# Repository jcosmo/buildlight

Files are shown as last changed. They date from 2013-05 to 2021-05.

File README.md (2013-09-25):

Buildlight 
==========
Arduino Uno based build light for Jenkins.

Arduino Uno has:
 - 6 PWM pins - 3,5,6,9,10,11
 - 6 Digital pins - 2,4,7,8,12,13
 - 6 Analog pins

Intend to support lights:
 - RGB: 3,5,6 + 5V
 - RGB: 9,10,11 + 5V
 - Shiftbrite: 7,8,12,13 + Pwr + Gnd
 - 8 * single colour led: 3xR, 2xG, 3xY: 2,4, A0->A5

Possible that digital pins 0 & 1 might be usable, but if you can't work with 11 lights then you're stuffed.
  
Specs for lights
  - Common Anode 4 pin Tri Colour
     Red: 2 -> 2.2 V
     Green: 3 -> 3.2 V
     Blue: 3 -> 3.2 V
  
  - Red led: No details, so presuming 2V -> 3.2V
  - Green led: No details, so presuming 2V -> 3.2V
  - Yellow led: No details, so presuming 2V -> 3.2V

Aim to pull about 20mA:  R = (5-Vl)/0.02
  3/0.02 => 150 Ohm
  1.8/0.02 => 90 Ohm
  
If we use 100Ohm, then current will be: I = (5-Vl/R)
  3/100 => 30mA
  1.8/100 => 18mA.
Both within tolerance of the Arduino pins (40mA max)
Concern? of drawing too much from one set of pins, or too much to the ground pin if multiple lights are on.

Experimentation in comparing 100 and 200 ohm resistors showed not enough difference to warrant 100Ohm for yellow and green.
So will go 200 and lower the current.  Red is notably dimmer than the others in all cases so will use a 100Ohm for it to increase brightness.

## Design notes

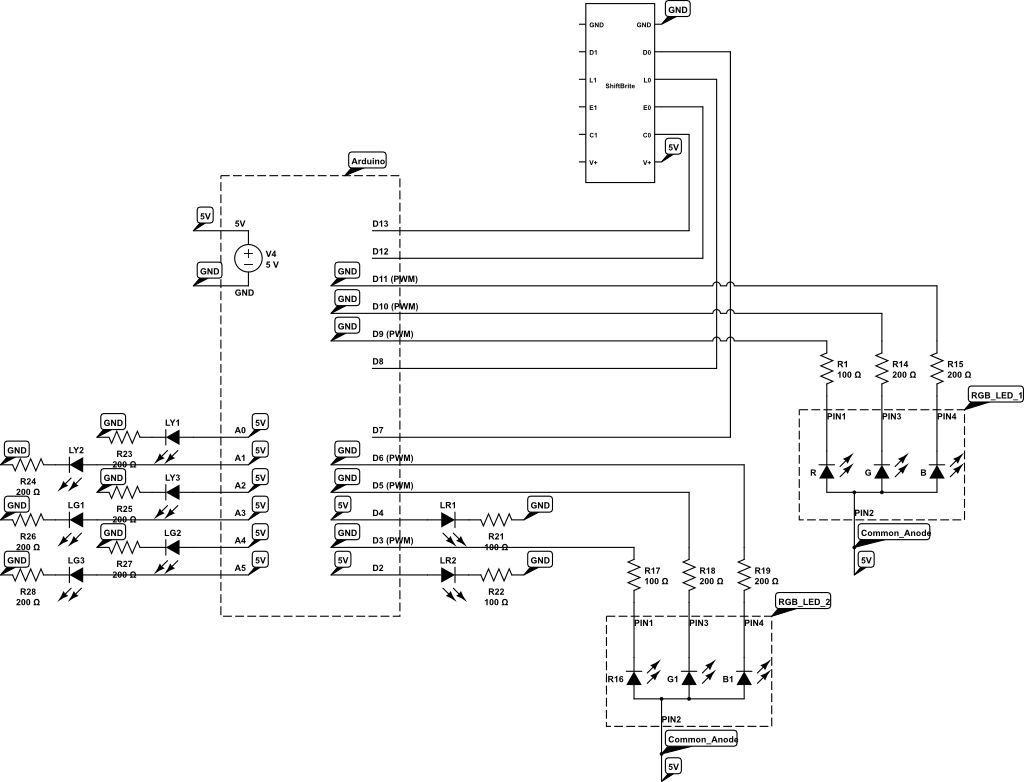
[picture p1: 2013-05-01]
circuit.png

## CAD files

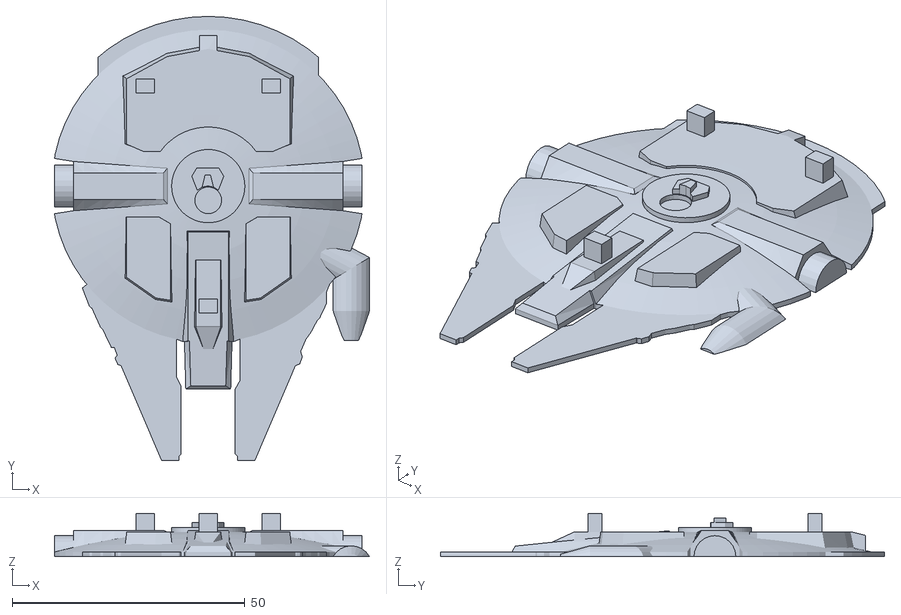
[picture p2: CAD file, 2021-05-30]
case/falcon2_bottom2.stl
67.6 x 95.3 x 9.28

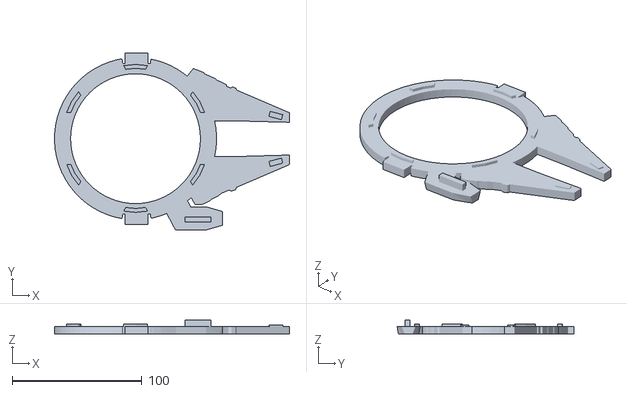
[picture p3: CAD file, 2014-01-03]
case/case_middle.stl
181.0 x 136.3 x 11.0

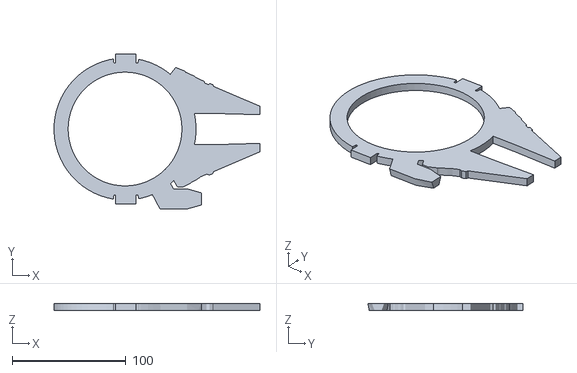
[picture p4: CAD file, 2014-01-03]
case/case_middle_noclips.stl
181.0 x 136.3 x 6.00

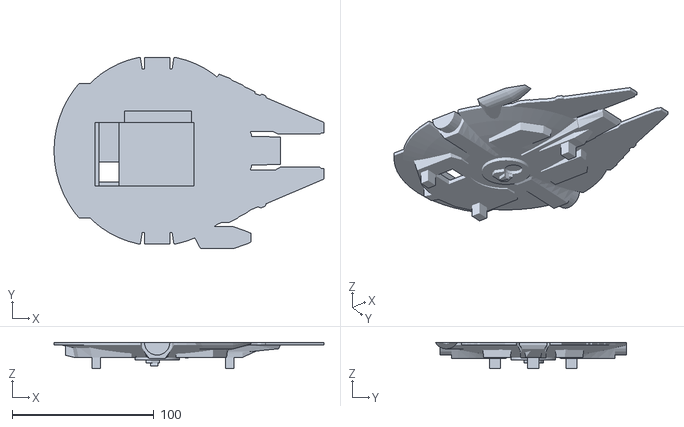
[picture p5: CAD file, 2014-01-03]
case/case_bottom_cleaned.stl
190.7 x 135.2 x 18.6

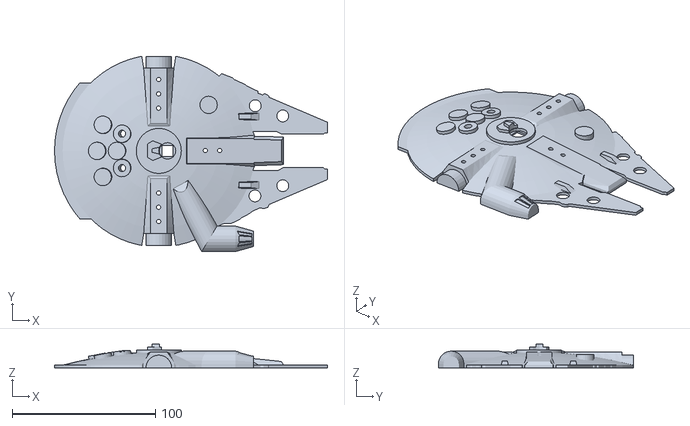
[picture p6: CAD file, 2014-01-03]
case/case_top_cleaned.stl
190.7 x 136.3 x 16.7

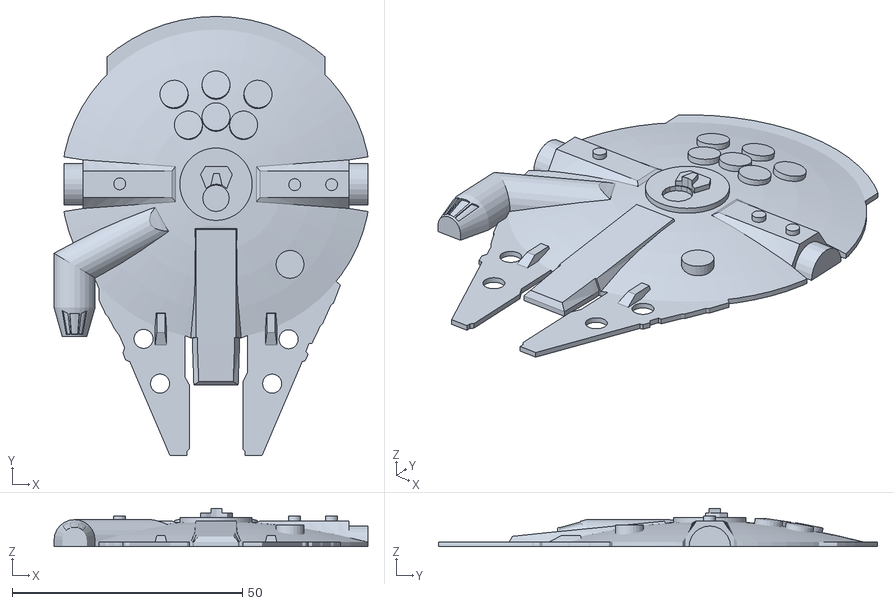
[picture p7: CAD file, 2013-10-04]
case/falcon2top_fixed.stl
68.2 x 95.3 x 8.35

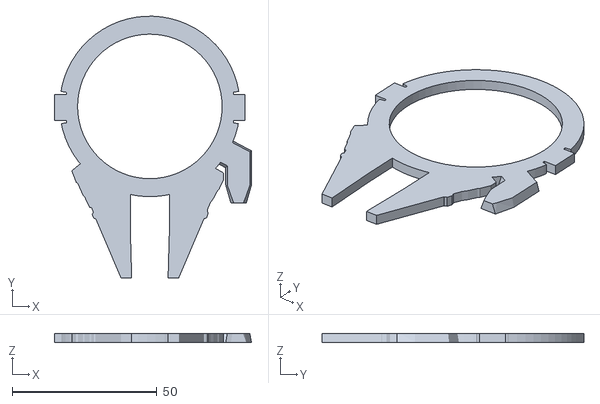
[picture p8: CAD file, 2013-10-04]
case/falcon2middle_fixed.stl
68.2 x 90.5 x 3.00

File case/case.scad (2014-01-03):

// Axis indexes;
X = 0; Y = 1; Z = 2;

FalconScale = 2;
FalconMOffset = [0,-2.41,0]; // Relative to FalconTop
FalconBOffset = [0.3,0,-3]; // Relative to FalconTop

FalconOffset = [FalconScale * 8.2, FalconScale * -1.1, FalconScale * 1.5]; // To Centre the Falcon
//ArduinoOffset = [0, 15+9.25, FalconScale * FalconBOffset[Z]/2];   // Relative to centred falcon
ArduinoOffset = [18, 5, 5.6];   // Relative to centred falcon
LedOffset = [-15.5, -10.5, 9.5];   // Relative to centred falcon

//echo( "Falcon at ", FalconScale, "x is ", (FalconScale * 95), " long, ", (FalconScale*70), " wide and ", (FalconScale*22), " tall" );
// scalebar();
difference() {
union() {
translate(FalconOffset) falcon(true,false,false);
//translate(ArduinoOffset) rotate([180,0,180]) arduino();
//translate(LedOffset) shiftbrite();
}
translate(ArduinoOffset) rotate([180,0,180]) arduino_cutout();
translate(LedOffset) shiftbrite_cutout();
wire_cutout();
}

module wire_cutout() {
  translate([-50,-25,-10]) cube([70,45,10]);
  translate([-40,-15,-20]) cylinder(r=7,h=10);
}

module arduino_cutout() {
  translate([0,-2.5,0] ) cube( [47, 25.5, 12.8] ); 
}

module shiftbrite_cutout() {
  union() {
    shiftbrite();
    translate([0,0,-10]) cube([31,21,11.4]);
  }
}

module arduino() {
  Board = [43.5, 18.5, 4.8];
  Usb = [9.5, 7.6, 3.75];
  Pins = [5, 7.5, 8.25];
  PinsWithSpace = [Pins[X]+3, Pins[Y]+3, Pins[Z]+2];
  
  UsbOffset = [Board[X] - (Usb[X] - 1.9), centre(Board, Usb, Y), Board[Z]];
  PinsOffset = [0, centre(Board, PinsWithSpace, Y), Board[Z]];

  color( "Black", 0.8) {
    cube( Board ); 
    translate( UsbOffset ) cube( Usb );
    translate( PinsOffset ) cube( PinsWithSpace );
  }
}

module shiftbrite() {
  Ledbase = [7.7,7.7,4.5];
  Leddome = 4.8;
  Board = [31,21,1.5];
  Pins = [16, 2.5, 12];
  
  LedbaseOffset = [centre(Board, Ledbase, X), centre(Board, Ledbase, Y), Board[Z]];
  LeddomeOffset = [Board[X]/2, Board[Y]/2, Ledbase[Z] + LedbaseOffset[Z]];
  Pin1Offset = [centre(Board, Pins, X), 1, -9];
  Pin2Offset = [centre(Board, Pins, X), Board[Y] - Pins[Y] - 1, -9];
  
  color( "Black", 1 ){
    cube(Board);
    translate( LedbaseOffset ) cube( Ledbase );
    translate( LeddomeOffset ) sphere( r=Leddome/2, $fn=20 );
  }
  color ("White", 1) {
    translate( Pin1Offset ) cube( Pins );
    translate( Pin2Offset ) cube( Pins );
  }
}

// holes at given spacing
module holes(count, size, spacing) {
  union() {
    for (x = [0:count-1]) translate([spacing*x,0,0]) cylinder(h=10,r=(size/FalconScale)/2, $fn=40);
  }
}

module middle_to_top_clips() {
  translate(FalconMOffset) {
    translate([1.2,14,0]) difference() {
      cylinder(r=28.5, h=1);
      cylinder(r=27, h=1);
      for( x = [0:5] ) rotate([0,0,x*60]) cube([20,60,5], center=true);
    }
    translate([-8,-40,0]) rotate([0,0,15]) cube([2,5,1], center=true);
    translate([10,-40,0]) rotate([0,0,-15]) cube([2,5,1], center=true);
    translate([-30,-10,0]) cube([2,10,5], center=true);
  }
}            

module falcon(top, middle, bottom) {
  O = 0.5;
  
  scale(FalconScale)
    rotate([0,0,90]) {
      if (top) {
        //color( "Salmon", O) 
        difference() {
          import( "falcon2top_fixed.stl" );
          translate([15,9,5.64]) cube([15,5,3]);	// remove bobbles on right
          translate([-26,9,5.64]) cube([15,5,3]);	// remove bobbles on left
          translate([16,11.3,-4]) holes(3, 3, 5);	
          translate([-23.6,11.3,-4]) holes(3, 3, 5);	
          translate([1.2,-10,-4]) rotate([0,0,90]) holes(2, 3, 5);
          translate([-4.9,23,-2]) rotate([-8,0,0]) holes(2, 5, 12);
          middle_to_top_clips();
        }
      }
      if (middle) {
//      color( "DarkSalmon", O) 
        translate(FalconMOffset) {
          rotate([0,180,0]) import( "falcon2middle_fixed.stl" );
        }
        //middle_to_top_clips();
      }
      if (bottom) {
//      color( "Salmon", O);
        translate(FalconBOffset) rotate([0,180,0]) import( "falcon2bottom_fixed.stl" );
      }
    }
}

module scalebar() {
  scale(FalconScale) {
    color("Blue", 1) {
      translate([-48,-1,-1]) cube([95, 2, 2]);
      rotate([0,0,90]) translate([-35,-1,-1]) cube([70, 2, 2]);
      rotate([0,90,0]) translate([-8,-1,-1]) cube([22, 2, 2]);
    }
  }
}

// Centre B in A along given axis
function centre( A, B, axis ) =
  (A[axis] - B[axis]) / 2;

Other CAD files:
case/case_bottom.stl
case/case_top.stl
case/falcon2bottom_fixed.stl
case/falcon2_middle.stl
case/falcon2_bottom.stl
case/falcon2_top.stl
case/bottom.skp
case/top.skp

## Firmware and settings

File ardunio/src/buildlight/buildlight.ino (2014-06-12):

/*
  Buildlight controller.

  Buildlight has RGB1, RGB2, Shiftbrite, 2xR + 3xG + 3xY led

  Commands:
      [light] ON/OFF/FLASH [Colour]?
      off  = everything off until next command
      flash [speed]
      sample

  [light]: T0, T1, S0, R0, R1, G0, G1, G2, Y0, Y1, Y2  (T => TriColour, S => ShiftBrite)
  [colour]: R,G,B optional, only used on T#, S#
  [speed]: milliseconds for each phase of a flash
*/

#include "HughesyShiftBrite.h"

typedef struct colour { unsigned int r; unsigned int g; unsigned int b; } Colour;
typedef struct { Colour colour; unsigned int pins[3]; bool on; bool flash; } RGBLed;
typedef struct { Colour colour; Colour offColour;
                 unsigned int data; unsigned int latch; unsigned int enable; unsigned int clock;
                 bool on; bool flash; HughesyShiftBrite hsb; } ShiftBrite;

RGBLed rgb_leds[2];
ShiftBrite shiftBrite[1];

unsigned int led_pins[] = {A5,2,4,A4,A1,A0,A2,A3};
bool led_on[8];
bool led_flash[8];
int RED_OFFSET = 0;
int YEL_OFFSET = RED_OFFSET + 4;
int GRN_OFFSET = YEL_OFFSET + 2;
int flash_speed = 250;
bool sleeping;

// RGB led colours for convienence
Colour RED = {0,255,255};
Colour GREEN = {255,0,255};
Colour BLUE = {255,255,0};
Colour YELLOW = {0,0,255};
Colour PURPLE = {0,255,0};
Colour CYAN = {255,0,0};
Colour WHITE = {0,0,0};
Colour SB_BLACK = {0,0,0};

void update_led( unsigned int idx )
{
  digitalWrite( led_pins[idx], led_on[idx] ? HIGH : LOW );
}

void set_led_flash( unsigned int idx )
{
  led_flash[idx] = true;
}

void toggle_led_state( unsigned int idx )
{
  led_on[idx] = !led_on[idx];
  update_led( idx );
}

void set_led_on( unsigned int idx )
{
  led_flash[idx] = false;
  led_on[idx] = true;
  update_led(idx);
}

void set_led_off( unsigned int idx )
{
  led_flash[idx] = false;
  led_on[idx] = false;
  update_led(idx);
}

void update_rgb( unsigned int idx )
{
  if ( rgb_leds[idx].on )
  {
    analogWrite(rgb_leds[idx].pins[0],rgb_leds[idx].colour.r);
    analogWrite(rgb_leds[idx].pins[1],rgb_leds[idx].colour.g);
    analogWrite(rgb_leds[idx].pins[2],rgb_leds[idx].colour.b);
  }
  else
  {
    analogWrite(rgb_leds[idx].pins[0],255);
    analogWrite(rgb_leds[idx].pins[1],255);
    analogWrite(rgb_leds[idx].pins[2],255);
  }
}

void set_rgb_colour_rgb( unsigned int idx, unsigned int r, unsigned int g, unsigned int b )
{
  rgb_leds[idx].colour.r = r;
  rgb_leds[idx].colour.g = g;
  rgb_leds[idx].colour.b = b;
  update_rgb(idx);
}

void set_rgb_colour( unsigned int idx, struct colour c )
{
  rgb_leds[idx].colour.r = c.r;
  rgb_leds[idx].colour.g = c.g;
  rgb_leds[idx].colour.b = c.b;
  update_rgb(idx);
}

void set_rgb_on( unsigned int idx )
{
  rgb_leds[idx].flash = false;
  rgb_leds[idx].on = true;
  update_rgb(idx);
}

void set_rgb_off( unsigned int idx )
{
  rgb_leds[idx].flash = false;
  rgb_leds[idx].on = false;
  update_rgb(idx);
}

void set_rgb_flash( unsigned int idx )
{
  rgb_leds[idx].flash = true;
}

void toggle_rgb_state( unsigned int idx )
{
  rgb_leds[idx].on = !rgb_leds[idx].on;
  update_rgb( idx );
}

void update_shiftBrite( unsigned int idx )
{
  if ( shiftBrite[idx].on )
    shiftBrite[idx].hsb.sendColour(shiftBrite[idx].colour.r,shiftBrite[idx].colour.g,shiftBrite[idx].colour.b);
  else
    shiftBrite[idx].hsb.sendColour(shiftBrite[idx].offColour.r,shiftBrite[idx].offColour.g,shiftBrite[idx].offColour.b);
}

float SB_RGB_SCALE = 1023/255;
void set_shiftBrite_colour( unsigned int idx, struct colour c )
{
  shiftBrite[idx].colour.r = (int)((255-c.r) * SB_RGB_SCALE);
  shiftBrite[idx].colour.g = (int)((255-c.g) * SB_RGB_SCALE);
  shiftBrite[idx].colour.b = (int)((255-c.b) * SB_RGB_SCALE);
  update_shiftBrite(idx);
}

void set_shiftBrite_offColour( unsigned int idx, struct colour c )
{
  shiftBrite[idx].offColour.r = (int)((255-c.r) * SB_RGB_SCALE);
  shiftBrite[idx].offColour.g = (int)((255-c.g) * SB_RGB_SCALE);
  shiftBrite[idx].offColour.b = (int)((255-c.b) * SB_RGB_SCALE);
}

void set_shiftBrite_flash( unsigned int idx )
{
  shiftBrite[idx].flash = true;
}

void toggle_shiftBrite_state( unsigned int idx )
{
  shiftBrite[idx].on = !shiftBrite[idx].on;
  update_shiftBrite(idx);
}

void set_shiftBrite_on( unsigned int idx )
{
  shiftBrite[idx].flash = false;
  if ( !shiftBrite[idx].on )
  {
    shiftBrite[idx].on = true;
    update_shiftBrite(idx);
  }
}

void set_shiftBrite_off( unsigned int idx )
{
  shiftBrite[idx].flash = false;
  set_shiftBrite_offColour( idx, (struct colour){255-SB_BLACK.r, 255-SB_BLACK.b, 255-SB_BLACK.g} );
  if ( shiftBrite[idx].on )
  {
    shiftBrite[idx].on = false;
    update_shiftBrite(idx);
  }
}

void sample_pattern()
{
  set_led_on( RED_OFFSET + 0 );
  set_led_flash( RED_OFFSET + 0 );
  set_led_flash( RED_OFFSET + 1 );
  set_led_flash( RED_OFFSET + 2 );
  set_led_flash( RED_OFFSET + 3 );
  set_led_on( GRN_OFFSET + 0 );
  set_led_flash( GRN_OFFSET + 0 );
  set_led_flash( GRN_OFFSET + 1 );
  
  set_led_flash( YEL_OFFSET + 0 );
  set_led_on( YEL_OFFSET + 1 );
  set_led_flash( YEL_OFFSET + 1 );

  set_led_on( RED_OFFSET + 1 );
  set_led_on( GRN_OFFSET + 1 );

  set_rgb_colour(0, WHITE );
  set_rgb_colour(1, PURPLE );
  set_rgb_on(1);
  set_rgb_flash(0);

  set_shiftBrite_colour(0, GREEN);
  set_shiftBrite_offColour(0, PURPLE);
  set_shiftBrite_flash(0);
}

void setup()
{
  rgb_leds[0] = (RGBLed){{255,255,255}, {3,6,5}, false, false};
  rgb_leds[1] = (RGBLed){{255,255,255}, {9,11,10}, false, false};
  shiftBrite[0] = (ShiftBrite){SB_BLACK, SB_BLACK, 7,8,12,13, false, false};

  for( unsigned int i = 0; i < sizeof(led_pins)/sizeof(led_pins[0]); i++)
  {
    led_on[i] = false;
    led_flash[i] = false;
    pinMode(led_pins[i], OUTPUT);
    update_led(i);
  }

  for( unsigned int i = 0; i < sizeof(rgb_leds)/sizeof(rgb_leds[0]); i++)
  {
    pinMode(rgb_leds[i].pins[0], OUTPUT);
    pinMode(rgb_leds[i].pins[1], OUTPUT);
    pinMode(rgb_leds[i].pins[2], OUTPUT);
    update_rgb(i);
  }

  for( unsigned int i = 0; i < sizeof(shiftBrite)/sizeof(shiftBrite[0]); i++)
  {
    pinMode(shiftBrite[i].enable, OUTPUT);
    pinMode(shiftBrite[i].clock, OUTPUT);
    pinMode(shiftBrite[i].data, OUTPUT);
    pinMode(shiftBrite[i].latch, OUTPUT);
    shiftBrite[i].hsb = HughesyShiftBrite( shiftBrite[i].data, shiftBrite[i].latch, shiftBrite[i].enable, shiftBrite[i].clock );
    update_shiftBrite(i);
  }  
  
  Serial.begin(9600);
  Serial.setTimeout(100);
}

void loop()
{
  if ( sleeping )
    delay( 30 * 1000 );
  else
  {
    for( unsigned int i = 0; i < sizeof(led_pins)/sizeof(led_pins[0]); i++)
      if ( led_flash[i] )
        toggle_led_state( i );

    for( unsigned int i = 0; i < sizeof(rgb_leds)/sizeof(rgb_leds[0]); i++)
      if ( rgb_leds[i].flash )
        toggle_rgb_state( i );

    for( unsigned int i = 0; i < sizeof(shiftBrite)/sizeof(shiftBrite[0]); i++)
      if ( shiftBrite[i].flash )
        toggle_shiftBrite_state( i );

    delay(flash_speed);
  }
}

void all_off()
{
  for( unsigned int i = 0; i < sizeof(led_pins)/sizeof(led_pins[0]); i++)
    set_led_off( i );

  for( unsigned int i = 0; i < sizeof(rgb_leds)/sizeof(rgb_leds[0]); i++)
    set_rgb_off( i );

  for( unsigned int i = 0; i < sizeof(shiftBrite)/sizeof(shiftBrite[0]); i++)
    set_shiftBrite_off( i );
}

void led_cmd( unsigned int offset, char *cmd )
{
  int idx;
  char op[80];
  if ( 2 == sscanf(cmd + sizeof(char), "%d %s", &idx, op))
  {
    if ( idx + offset >= sizeof(led_pins)/sizeof(led_pins[0]))
    {
      Serial.println(String("Invalid led pin index: [") + idx + "]");
      return;
    }
    if ( String("ON").equalsIgnoreCase(op) )
      set_led_on( idx + offset );
    else if ( String("OFF").equalsIgnoreCase(op) )
      set_led_off( idx + offset );
    else if ( String("FLASH").equalsIgnoreCase(op) )
      set_led_flash( idx + offset );
    else
      Serial.println(String("Invalid led pin command: [") + op + "]");
  }
  else
    Serial.println(String("Invalid LED command structure: ") + cmd);
}

void rgb_cmd_colour( int idx, char *colour )
{
  int r,g,b;
  if ( sscanf( colour, "%d,%d,%d", &r, &g, &b) == 3 )
  {
    set_rgb_colour( idx, (struct colour){255-constrain(r, 0, 255), 255-constrain(g, 0, 255), 255-constrain(b, 0, 255)} );
  }
}

void rgb_cmd( char *cmd )
{
  int idx;
  char op[80];
  char arg[80];
  int r,g,b;
  if ( sscanf(cmd + sizeof(char), "%d %s %s", &idx, op, arg) >= 2)
  {
    if ( idx >= sizeof(rgb_leds)/sizeof(rgb_leds[0]))
    {
      Serial.println(String("Invalid tri-colour index: [") + idx + "]");
      return;
    }
    if ( String("ON").equalsIgnoreCase(op) )
    {
      rgb_cmd_colour( idx, arg );
      set_rgb_on( idx );
    }
    else if ( String("OFF").equalsIgnoreCase(op) )
      set_rgb_off( idx  );
    else if ( String("FLASH").equalsIgnoreCase(op) )
    {
      rgb_cmd_colour( idx, arg );
      set_rgb_flash( idx );
    }
    else
      Serial.println(String("Invalid tri-colour command: [") + op + "]");
  }
  else
    Serial.println(String("Invalid tri-colour command structure: ") + cmd);
}

void sb_cmd_colour( int idx, char *colour )
{
  int r,g,b, oR,oG,oB;
  if ( sscanf( colour, "%d,%d,%d %d,%d,%d", &r, &g, &b, &oR, &oG, &oB) == 6 )
  {
    set_shiftBrite_colour( idx, (struct colour){255-constrain(r, 0, 255), 255-constrain(g, 0, 255), 255-constrain(b, 0, 255)} );
    set_shiftBrite_offColour( idx, (struct colour){255-constrain(oR, 0, 255), 255-constrain(oG, 0, 255), 255-constrain(oB, 0, 255)} );
  }
  else if ( sscanf( colour, "%d,%d,%d", &r, &g, &b ) == 3 )
  {
    set_shiftBrite_colour( idx, (struct colour){255-constrain(r, 0, 255), 255-constrain(g, 0, 255), 255-constrain(b, 0, 255)} );
  }
}

void sb_cmd( char *cmd )
{
  int idx;
  char op[80];
  char arg[80];
  int r,g,b;
  if ( sscanf(cmd + sizeof(char), "%d %s %[^\n]", &idx, op, arg) >= 2)
  {
    if ( idx >= sizeof(shiftBrite)/sizeof(shiftBrite[0]))
    {
      Serial.println(String("Invalid shiftBrite index: [") + idx + "]");
      return;
    }
    if ( String("ON").equalsIgnoreCase(op) )
    {
      sb_cmd_colour( idx, arg );
      set_shiftBrite_on( idx );
    }
    else if ( String("OFF").equalsIgnoreCase(op) )
      set_shiftBrite_off( idx );
    else if ( String("FLASH").equalsIgnoreCase(op) )
    {
      sb_cmd_colour( idx, arg );
      set_shiftBrite_flash( idx );
    }
    else
      Serial.println(String("Invalid shiftBrite command: [") + op + "]");
  }
  else
    Serial.println(String("Invalid shiftBrite command structure: ") + cmd);
}

void serialEvent() {
  char   cmd_str[80];
  int    cmd_length;
  int    led_value;
  cmd_length = Serial.readBytesUntil('\n', cmd_str, 79);
  cmd_str[cmd_length] = '\0';

  /*
    Commands:
        [light] ON/OFF/FLASH [Colour]?
        off  = everything off until next command
        flash [speed]
        sample

    [light]: T0, T1, S0, R0, R1, G0, G1, G2, Y0, Y1, Y2  (T => TriColour, S => ShiftBrite)
    [colour]: R,G,B optional, only used on T#, S#
    [speed]: milliseconds for each phase of a flash
  */
  int arg;
  if ( String(cmd_str).equalsIgnoreCase("off") )
  {
    all_off();
    sleeping = true;
  }
  else if ( sscanf(cmd_str, "flash %d", &arg) == 1 )
    flash_speed = arg;
  else if ( String(cmd_str).equalsIgnoreCase("sample") )
    sample_pattern();
  else
  {
    sleeping = false;
    switch(cmd_str[0]) {
      case 'R': case 'r': led_cmd(RED_OFFSET, cmd_str);    break;
      case 'G': case 'g': led_cmd(GRN_OFFSET, cmd_str);    break;
      case 'Y': case 'y': led_cmd(YEL_OFFSET, cmd_str);    break;
      case 'T': case 't': rgb_cmd(cmd_str);    break;
      case 'S': case 's': sb_cmd(cmd_str);    break;
      default:
          Serial.println(String("Unrecognised command: ") + cmd_str);
    }
  }
}

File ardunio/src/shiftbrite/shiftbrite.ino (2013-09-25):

/*
  Control a ShiftBrite 
  
  Change colour of led by sending appropriate command via USB
  Command takes the form of either
    R|G|B|O   - to turn on Red/Green/Blue/None at full intensity
  or
    Q|W|E|A # - to control the intensity (#) of the Red/Green/Blue/White component of the current colour
*/

#include "HughesyShiftBrite.h"

#define ORIENTATION 1
#define POWER_pin 2
#define CLOCK_pin  (POWER_pin + ORIENTATION)
#define ENABLE_pin   (CLOCK_pin + ORIENTATION)
#define LATCH_pin   (ENABLE_pin + ORIENTATION)
#define DATA_pin   (LATCH_pin + ORIENTATION)
#define GND_pin  (DATA_pin + ORIENTATION)

#define INTENSITY 1023

HughesyShiftBrite led;
int flash_r;
int flash_g;
int flash_b;
boolean flash;

void setup() {
  pinMode(POWER_pin, OUTPUT);     
  pinMode(GND_pin, OUTPUT);     

  digitalWrite(GND_pin, LOW); 
  digitalWrite(POWER_pin, HIGH); 

  led = HughesyShiftBrite( DATA_pin, LATCH_pin, ENABLE_pin, CLOCK_pin );
  off();
  
  Serial.begin(9600);
  Serial.setTimeout(100);
}

void loop() {
  if ( flash ) {
    delay(500);
    led.sendColour(0,0,0);
    delay(500);    
    led.sendColour(flash_r,flash_g,flash_b);
  }
}

void serialEvent() {  
  char   cmd_str[80];
  int    cmd_length;
  int    led_value;
  cmd_length =   Serial.readBytesUntil('\n', cmd_str, 80);
  cmd_str[cmd_length] = '\0';
  switch(cmd_str[0]) {
    case 'R': red();      break;
    case 'G': green();   break;
    case 'B': blue();     break;
    case 'Y': yellow();  break;
    case 'O': off();      break;
    case 'F': toggle_flash();      break;
  }
}

void update_led(int R, int G, int B) {
  led.sendColour(R, G, B);
  flash_r = R;
  flash_g = G;
  flash_b = B;
}



// Translate a value from rgb (0->255) to shiftbrite (0->1023)
int SCALE = 1023/255;
unsigned int x( unsigned int rgb ) {
  return rgb * SCALE;
}

void red() {  update_led(INTENSITY,0,0); }
void green() {  update_led(0,INTENSITY,0); }
void blue() {  update_led(0,0,INTENSITY); }
void yellow() {  update_led(x(255),x(128),0); }
void off() { flash = false; update_led(0,0,0); }

void toggle_flash() { flash = !flash; }

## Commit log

2013-01-06 Experiment with using 3 different leds. Just cycles through them without any smarts.
2013-01-06 Experiment with using a single led which can be tuned to any colour. Control the colour via serial comms.
2013-01-07 Start working on modelling the case
    [case.scad, falcon2_bottom.stl, falcon2_middle.stl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]
2013-01-08 Scale Falcon to 2x, results in nice size result: "Falcon is 190 long, 140 wide and 44 tall"
    [case.scad]
2013-01-09 Add model of shiftbrite, and position where it should go
    [case.scad]
2013-01-13 More experimentation with rgb led, now actually understand what it's doing so can write code that makes sense
2013-05-01 Add circuit diagram
2013-09-25 Implement flashing for basic leds
2013-09-26 Cleaner code for led flashing
2013-09-26 Implement control of rgb leds
2013-10-01 Implement serial control of basic leds
2013-10-01 Switch instead of if-else cascade
2013-10-01 Simplify 'led_on' and 'led_off' methods
2013-10-01 Bug fix - tri colour leds should stop flashing when forced on or off
    [buildlight.ino]
2013-10-01 Implement control of tri-colour leds
2013-10-01 Implement shiftBrite control. Direct copy/search-replace from tri-colour leds - means we should clean up this code.
    [buildlight.ino]
2013-10-04 Add 'fixed' versions (via netfab cloud) of case stls.
    [falcon2bottom_fixed.stl, falcon2middle_fixed.stl, falcon2top_fixed.stl]
2013-10-04 Work on cutting holes for leds to go through top of the case
    [case.scad]
2013-10-05 Add led holes
    [case.scad]
2014-01-03 Version to match what has actually been wired
2014-01-03 Latest case.
    Needs some mod in sketchup post render to make slicing of the cutouts feasible.
    [case.scad]
2014-01-03 bottom & top stl files from openscad.
    [case_bottom.stl, case_top.stl]
2014-01-03 Sketchup files for top & bottom after cleanup for printing
    [bottom.skp, case_bottom_cleaned.stl, case_top_cleaned.stl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]
2014-01-03 Middle of case
    [case_middle.stl, case_middle_noclips.stl]
2014-01-05 Remove debug Add command for setting up sample pattern (old debug pattern)
2021-05-30 stuff I had on my disk, no idea how current it is
    [falcon2_bottom2.stl]
